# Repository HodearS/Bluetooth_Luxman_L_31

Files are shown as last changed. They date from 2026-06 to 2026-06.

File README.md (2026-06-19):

### 🇫🇷 Version Française
                    
# Luxman L-31 - Module Bluetooth & DAC Interne

Ce dépôt contient les fichiers de conception matérielle d'une carte d'extension Bluetooth conçue spécifiquement pour s'intégrer à l'intérieur d'un amplificateur intégré Luxman L-31.

L'objectif est d'ajouter une connectivité sans fil moderne (aptX-HD) sans dénaturer l'esthétique d'origine de l'appareil ni altérer la qualité de son chemin analogique.

## Architecture technique

La carte s'alimente directement sur le rail de puissance interne de l'amplificateur (environ 40V DC). Le basculement du signal audio est géré par un relais de signal pour garantir que les entrées analogiques d'origine restent totalement isolées lorsque le module est inactif.

Points clés de la conception :
* **Alimentation :** Utilisation d'un régulateur abaisseur (Buck) acceptant jusqu'à 65V en entrée pour tolérer les variations du rail d'alimentation du Luxman.
* **CEM et Bruit :** Le convertisseur Buck fonctionne en mode "Forced PWM" (fréquence fixe de 400 kHz) afin de repousser le bruit de découpage hors de la bande audible. Le routage sur 4 couches inclut des plans de masse dédiés, du via stitching et des zones d'exclusion RF strictes autour de l'antenne.
* **Chemin audio :** Les composants passifs traitant le signal analogique en sortie de DAC utilisent des condensateurs à diélectrique C0G/NP0 et des résistances à couche mince (thin film) pour éviter l'introduction de distorsions harmoniques.

## Spécifications matérielles

* **Logiciel CAO :** KiCad 10
* **PCB :** 4 couches
* **Régulateur 5V :** Texas Instruments LMR51606XFDBVR
* **LDO 3.3V :** Texas Instruments TPS7A2033PDBVR (avec décharge active)
* **DAC :** ESS Technology ES9023P
* **Module Bluetooth :** Feasycom FSC-BT1026E (sortie I2S/PCM)
* **Relais Audio :** Omron G6K-2F-Y DC3

## Structure du dépôt

Ce dépôt héberge uniquement les fichiers sources du projet KiCad (`.kicad_pro`, `.kicad_sch`, `.kicad_pcb` et BOM). Les fichiers de fabrication (Gerbers, fichiers de placement CPL) ne sont pas versionnés.

## Avertissement de sécurité

L'installation de ce module implique d'intervenir à l'intérieur d'un amplificateur relié au secteur et de manipuler des tensions continues de puissance. Ces modifications s'adressent à des personnes ayant les compétences requises en électronique. Toute modification est effectuée à vos propres risques.

### 🇬🇧 English Version

# Luxman L-31 - Internal Bluetooth & DAC Module

This repository contains the hardware design files for a Bluetooth extension board specifically designed to be integrated inside a Luxman L-31 integrated amplifier.

The goal is to add modern wireless connectivity (aptX-HD) without altering the original aesthetics of the device or degrading its analog signal path.

## Technical Architecture

The board is powered directly from the amplifier's internal power rail (approx. 40V DC). Audio signal switching is handled by a signal relay to ensure the original analog inputs remain completely isolated when the module is inactive.

Key design points:
* **Power Supply:** Use of a step-down (Buck) regulator accepting up to 65V input to tolerate fluctuations in the Luxman's power rail.
* **EMC and Noise:** The Buck converter operates in "Forced PWM" mode (fixed 400 kHz frequency) to push switching noise out of the audible band. The 4-layer routing includes dedicated ground planes, via stitching, and strict RF keep-out zones around the antenna.
* **Audio Path:** Passive components handling the analog signal at the DAC output use C0G/NP0 dielectric capacitors and thin film resistors to prevent the introduction of harmonic distortion.

## Hardware Specifications

* **CAD Software:** KiCad 10
* **PCB:** 4 layers
* **5V Regulator:** Texas Instruments LMR51606XFDBVR
* **3.3V LDO:** Texas Instruments TPS7A2033PDBVR (with active discharge)
* **DAC:** ESS Technology ES9023P
* **Bluetooth Module:** Feasycom FSC-BT1026E (I2S/PCM output)
* **Audio Relay:** Omron G6K-2F-Y DC3

## Repository Structure

This repository hosts only the KiCad project source files (`.kicad_pro`, `.kicad_sch`, `.kicad_pcb` and BOM). Manufacturing files (Gerbers, CPL placement files) are not versioned.

## Safety Warning

Installing this module involves working inside a mains-connected amplifier and handling high-power DC voltages. These modifications are intended for individuals with the required electronics skills. All modifications are performed at your own risk.

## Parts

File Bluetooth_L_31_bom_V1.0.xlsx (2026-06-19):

Component | References | Description | Value | Footprint | Quantity Per PCB | Prix/unité | Total | Quantité/commande | Total/commande
1 | C15 | GRM2165C2A331JA01D | 330pF | C_0805_2012Metric | 1 | 0.074 | 0.074 | 10 | 0.74
2 | C5 C7 | 08051A472KAT2A | 4700pF | C_0805_2012Metric | 2 | 0.295 | 0.59 | 10 | 2.95
3 | C1 C11 C14 C23 C24 | CL21B104KCFSFNE | 100nF | C_0805_2012Metric | 5 | 0.027 | 0.135 | 20 | 0.54
4 | C2 C3 C9 C10 C13 C16 C17 C22 | CL21B105KBFNNNF | 1uF | C_0805_2012Metric | 8 | 0.038 | 0.304 | 20 | 0.76
5 | C19 | CL21B225KAFNNNF | 2.2uF | C_0805_2012Metric | 1 | 0.041 | 0.041 | 10 | 0.41
6 | C6 C8 | GRM32DL8EL475KE07L | 4.7uF | C_1210_3225Metric | 2 | 0.0361 | 0.0722 | 10 | 0.361
7 | C12 C20 C21 | GRM21BZ71E106KE15K | 10uF | C_0805_2012Metric | 3 | 0.119 | 0.357 | 10 | 1.19
8 | C4 | CL32B106KMVNNWE | 10uF | C_1210_3225Metric | 1 | 0.38 | 0.38 | 10 | 3.8
9 | C18 | CL32B226KAJNNNE | 22uF | C_1210_3225Metric | 1 | 0.238 | 0.238 | 10 | 2.38
10 | D3 | 100V 0.15A standard switching diode, DO-35 | 1N4148 | D_SOD-123 | 1 | 0.087 | 0.087 | 10 | 0.87
11 | D1 | B360-13-F | B360 | D_SMC | 1 | 0.35 | 0.35 | 10 | 3.5
12 | D4 | 150080GS75000 | LED | LED_0805_2012Metric | 1 | 0.161 | 0.161 | 10 | 1.61
13 | D2 | SMAJ48A | SMAJ48A | D_SMA | 1 | 0.275 | 0.275 | 10 | 2.75
14 | J1 | 1727010 | 1727010 | PHOENIX_1727010 | 1 | 0.972 | 0.972 | 2 | 1.944
15 | J2 J3 | 1727023 | 1727023 | PHOENIX_1727023 | 2 | 1.45 | 2.9 | 4 | 5.8
16 | J4 | B3B-PH-SM4-TB(LF)(SN) | B3B-PH-SM4-TB_LF__SN_ | JST_B3B-PH-SM4-TB_LF__SN_ | 1 | 0.387 | 0.387 | 2 | 0.774
17 | K1 | G6K-2F-Y-DC3 | G6K-2F-Y DC3 | Relay_DPDT_Omron_G6K-2F-Y | 1 | 3.15 | 3.15 | 2 | 6.3
18 | L1 | LQH32PN1R0NN0L | 820nH | L_1210_3225Metric | 1 | 0.188 | 0.188 | 10 | 1.88
19 | L2 | SRN4018-470M | 47uH | L_Bourns-SRN4018 | 1 | 0.264 | 0.264 | 10 | 2.64
20 | Q1 Q2 | 2N7002LT1G | 2N7002 | SOT-23-3 | 2 | 0.164 | 0.328 | 10 | 1.64
21 | R6 R9 | Resistor, small symbol | 100m | R_0805_2012Metric | 2 (DNF) |  |  |  | 0
22 | R3 | Resistor, small symbol | 1 | R_0805_2012Metric | 1 (DNF) |  |  |  | 0
23 | R10 | RC0805FR-073RL | 3 | R_0805_2012Metric | 1 | 0.024 | 0.024 | 10 | 0.24
24 | R4 R20 R21 R22 | RC0805FR-0733RL | 33 | R_0805_2012Metric | 4 | 0.015 | 0.06 | 10 | 0.15
25 | R2 R5 | ERA-6AEB471V | 470 | R_0805_2012Metric | 2 | 0.064 | 0.128 | 10 | 0.64
26 | R14 R17 R19 | RC0805FR-071KL | 1k | R_0805_2012Metric | 3 | 0.018 | 0.054 | 10 | 0.18
27 | R1 R8 R16 R23 | RC0805FR-0710KL | 10k | R_0805_2012Metric | 4 | 0.018 | 0.072 | 10 | 0.18
28 | R12 | RC0805FR-0719K1L | 19.1k | R_0805_2012Metric | 1 | 0.017 | 0.017 | 10 | 0.17
29 | R11 R13 R15 R18 | RC0805FR-07100KL | 100k | R_0805_2012Metric | 4 | 0.018 | 0.072 | 10 | 0.18
30 | R7 | RC0805FR-07280KL | 280k | R_0805_2012Metric | 1 | 0.015 | 0.015 | 10 | 0.15
31 | SW1 | B3U-1000PM | B3U-1000P(M) | SW_B3U-1000PM | 1 | 1.08 | 1.08 | 1 | 1.08
32 | U5 | FSC-BT1026E | FSC-BT1026E | FSC-BT1026x | 1 | 8 | 8 | 1 | 8
33 | U3 | LMR51606XFQDBVRQ1 | LMR51606FPWM | SOT-23-6 | 1 | 1.4 | 1.4 | 1 | 1.4
34 | U1 U2 | TPS7A2033PDBVR | ~ | SOT-23-5 | 2 | 0.224 | 0.448 | 5 | 1.12
35 | U4 | ES9023P | ~ | SOP-16_4.4x10.4mm_P1.27mm | 1 | 1.19 | 1.19 | 4 | 4.76
36 | Y1 | SG-210STF 50.0000ML | SG-210STF 50.0000ML | Oscillator_SMD_SeikoEpson_SG210-4Pin_2.5x2.0mm | 1 | 2.12 | 2.12 | 1 | 2.12
 |  |  |  |  |  | Coût total/cartes | 25.9332 | 283 | 63.209
Component Groups: | 36
Component Count: | 67
Fitted Components: | 64
Number of PCBs: | 1
Total components: | 64
Schematic Version: | V1.0
Schematic Date: | 2026-06-17
BoM Date: | 2026-06-19T23:25:48
Schematic Source: | Bluetooth_L_31.kicad_sch
KiCad Version: | Eeschema 10.0.3

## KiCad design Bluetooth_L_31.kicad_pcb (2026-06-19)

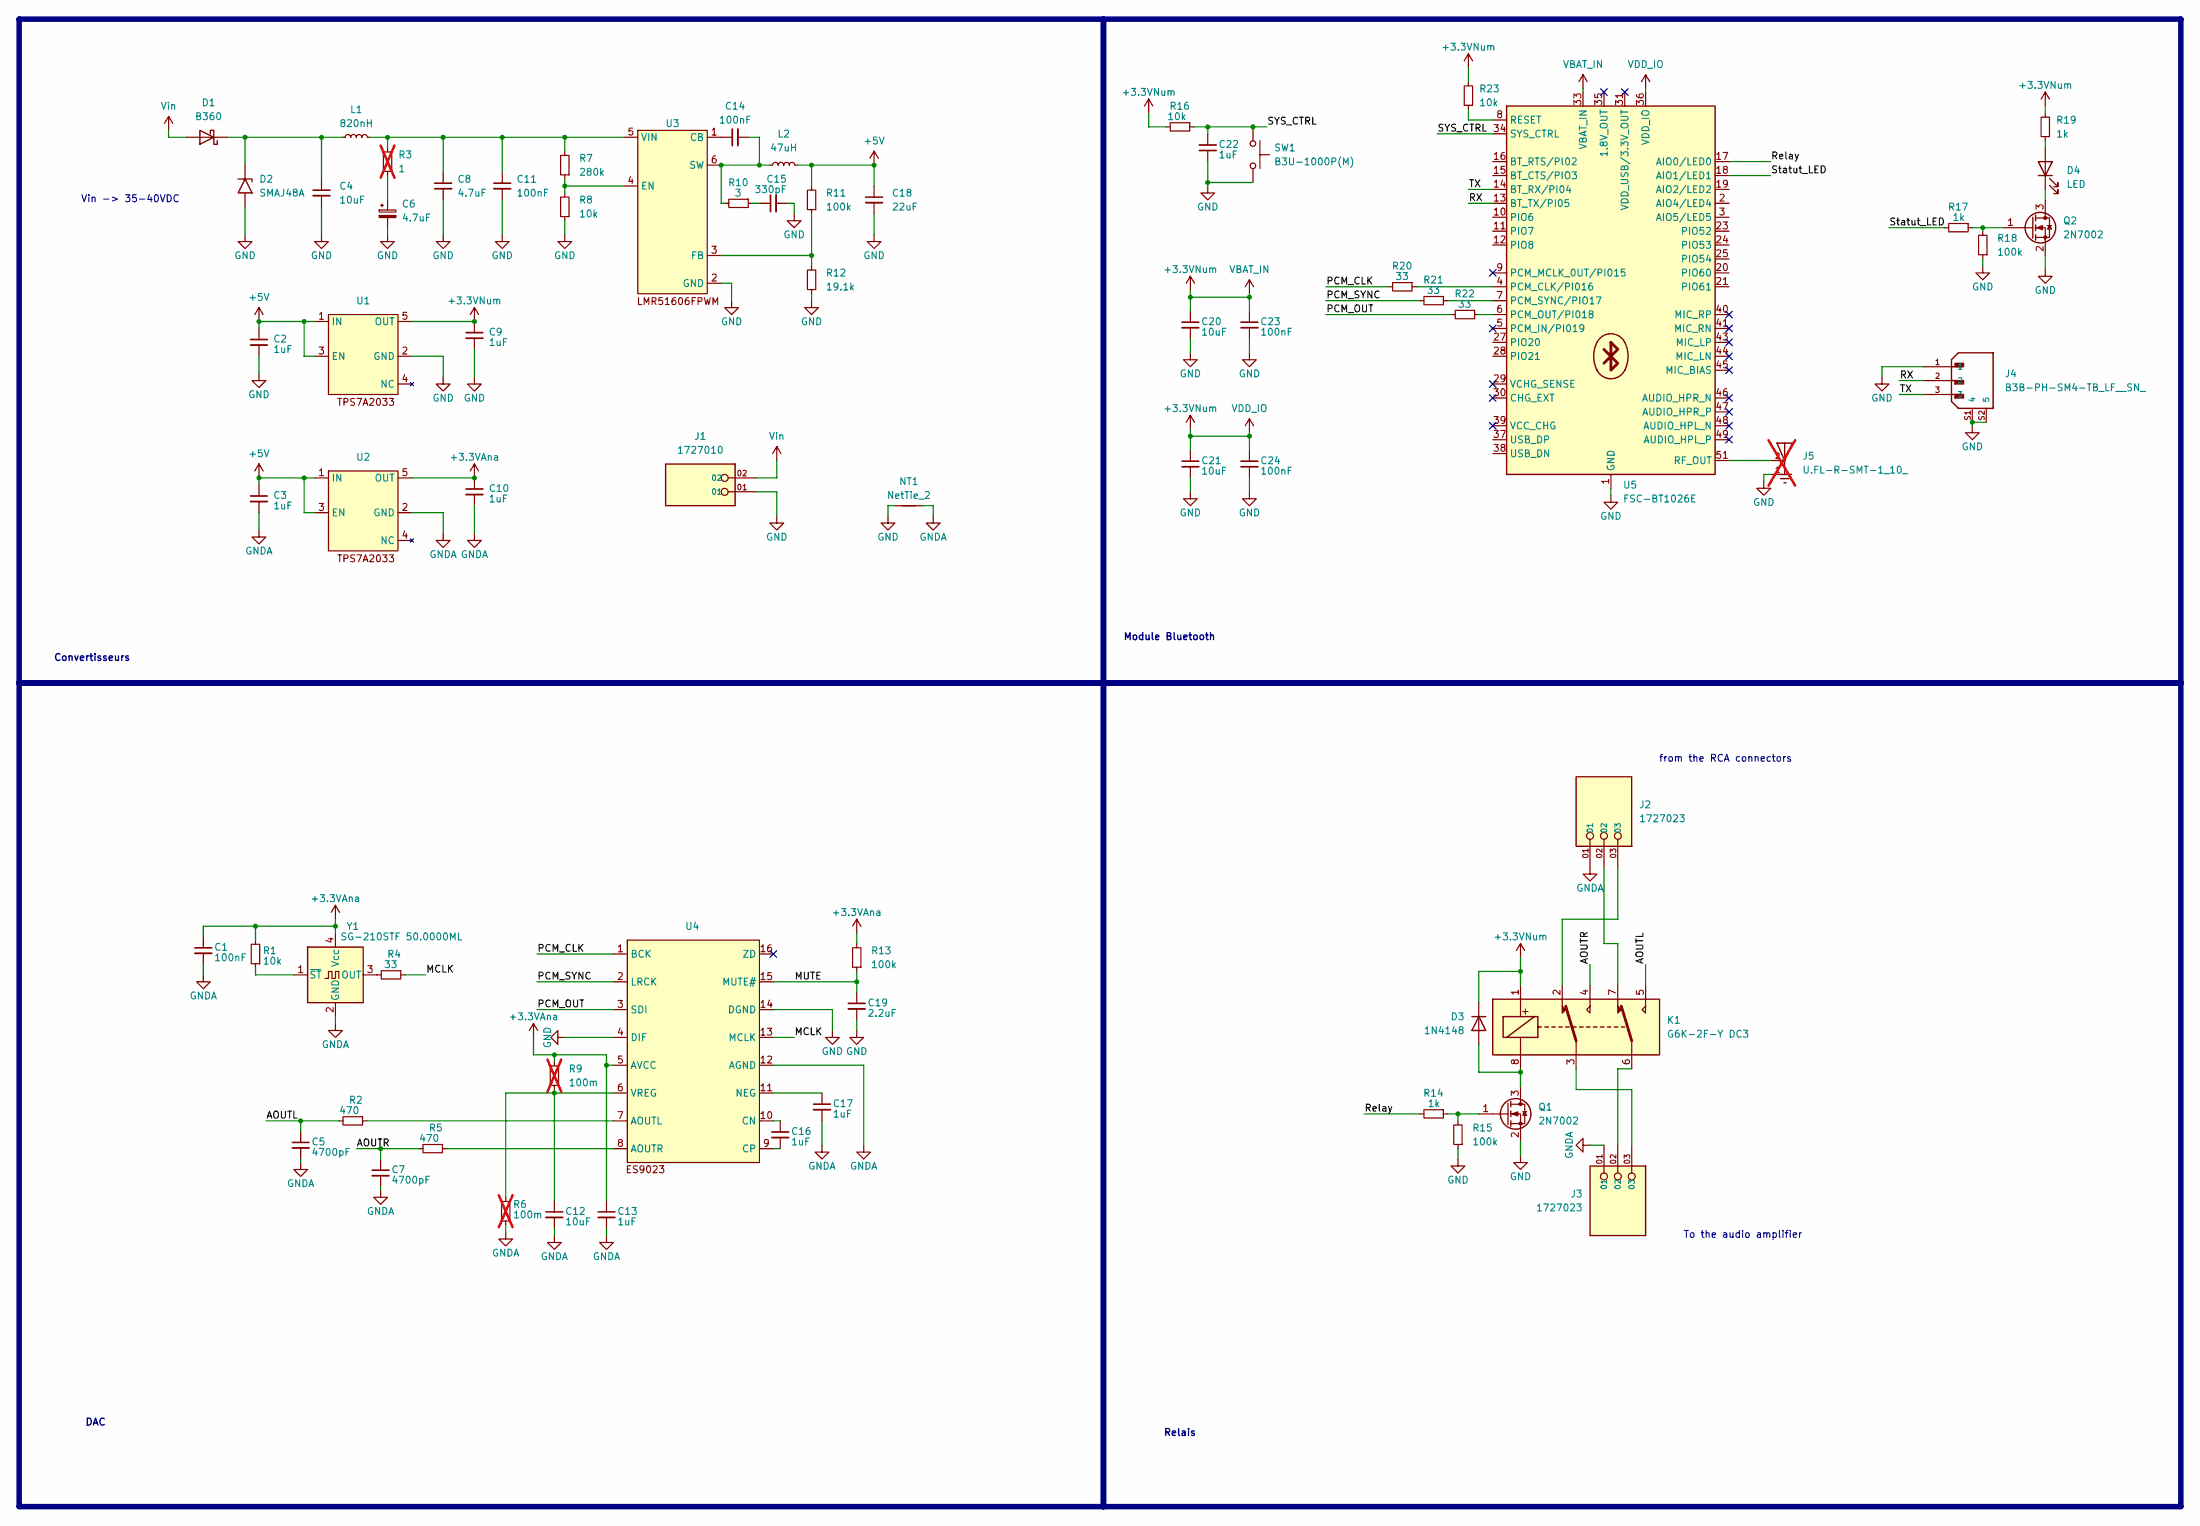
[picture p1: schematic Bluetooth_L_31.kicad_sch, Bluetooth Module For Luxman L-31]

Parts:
C1, C11, C14, C23, C24: 100nF; C_0805_2012Metric
C2, C3, C9, C10, C13, C16, C17, C22: 1uF; C_0805_2012Metric
C4: 10uF; C_1210_3225Metric
C5, C7: 4700pF; C_0805_2012Metric
C6, C8: 4.7uF; C_1210_3225Metric
C12, C20, C21: 10uF; C_0805_2012Metric
C15: 330pF; C_0805_2012Metric
C18: 22uF; C_1210_3225Metric
C19: 2.2uF; C_0805_2012Metric
D1: B360; D_SMC
D2: SMAJ48A; D_SMA
D3: 1N4148; D_SOD-123
D4: LED; LED_0805_2012Metric
J1: 1727010; PHOENIX_1727010; PARTREV 03.03.2021
J2, J3: 1727023; PHOENIX_1727023; PARTREV 03.03.2021
J4: B3B-PH-SM4-TB_LF__SN_; JST_B3B-PH-SM4-TB_LF__SN_; PARTREV N/A
J5: U.FL-R-SMT-1_10_; HRS_U.FL-R-SMT-1_10_; not fitted
K1: G6K-2F-Y DC3; Relay_DPDT_Omron_G6K-2F-Y
L1: 820nH; L_1210_3225Metric
L2: 47uH; L_Bourns-SRN4018
NT1: NetTie_2; NetTie-2_SMD_Pad2.0mm
Q1, Q2: 2N7002; SOT-23-3
R1, R8, R16, R23: 10k; R_0805_2012Metric
R2, R5: 470; R_0805_2012Metric
R3: 1; R_0805_2012Metric; not fitted
R4, R20, R21, R22: 33; R_0805_2012Metric
R6, R9: 100m; R_0805_2012Metric; not fitted
R7: 280k; R_0805_2012Metric
R10: 3; R_0805_2012Metric
R11, R13, R15, R18: 100k; R_0805_2012Metric
R12: 19.1k; R_0805_2012Metric
R14, R17, R19: 1k; R_0805_2012Metric
SW1: B3U-1000P(M); SW_B3U-1000PM
U1, U2: SOT-23-5
U3: LMR51606FPWM; SOT-23-6
U4: SOP-16_4.4x10.4mm_P1.27mm
U5: FSC-BT1026E; FSC-BT1026x
Y1: SG-210STF 50.0000ML; Oscillator_SMD_SeikoEpson_SG210-4Pin_2.5x2.0mm

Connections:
+3.3VAna: C1.1, C10.1, C13.1, R1.2, R9.2, R13.2, U2.5 (OUT), U4.5 (AVCC), Y1.4 (Vcc)
+3.3VNum: C9.1, C20.1, C21.1, C23.1, C24.1, D3.1 (K), K1.1, R16.2, R19.2, R23.2, U1.5 (OUT), U5.33 (VBAT_IN), U5.36 (VDD_IO)
+5V: C2.1, C3.1, C18.1, L2.2, R11.2, U1.1 (IN), U1.3 (EN), U2.1 (IN), U2.3 (EN)
/AOUTL: C5.1, K1.5, R2.2
/AOUTR: C7.1, K1.4, R5.2
/MCLK: R4.1, U4.13 (MCLK)
/MUTE: C19.1, R13.1, U4.15 (MUTE#)
/PCM_CLK: R20.2, U4.1 (BCK)
/PCM_OUT: R22.2, U4.3 (SDI)
/PCM_SYNC: R21.2, U4.2 (LRCK)
/RX: J4.2, U5.13 (BT_TX/PI05)
/Relay: R14.2, U5.17 (AIO0/LED0)
/SYS_CTRL: C22.1, R16.1, SW1.1, U5.34 (SYS_CTRL)
/Statut_LED: R17.2, U5.18 (AIO1/LED1)
/TX: J4.3, U5.14 (BT_RX/PI04)
GND: C2.2, C4.2, C6.2, C8.2, C9.2, C11.2, C15.2, C18.2, C19.2, C20.2, C21.2, C22.2, C23.2, C24.2, D2.2 (A2), J1.01, J4.1, J4.S1 (4), J4.S2 (5), J5.1, J5.3, NT1.1, Q1.2 (S), Q2.2 (S), R8.1, R12.1, R15.1, R18.1, SW1.2, U1.2 (GND), U3.2 (GND), U4.4 (DIF), U4.14 (DGND), U5.1 (GND), U5.22 (GND), U5.32 (GND), U5.50 (GND), U5.52 (GND)
GNDA: C1.2, C3.2, C5.2, C7.2, C10.2, C12.2, C13.2, C17.2, J2.01, J3.01, NT1.2, R6.1, U2.2 (GND), U4.12 (AGND), Y1.2 (GND)
unnamed: C6.1, R3.1
unnamed: C15.1, R10.1
unnamed: C4.1, D1.1 (K), D2.1 (A1), L1.1
unnamed: D3.2 (A), K1.8, Q1.3 (D)
unnamed: D4.2 (A), R19.1
unnamed: D4.1 (K), Q2.3 (D)
unnamed: J2.02, K1.7
unnamed: J2.03, K1.2
unnamed: J3.02, K1.6
unnamed: J3.03, K1.3
unnamed: Q1.1 (G), R14.1, R15.2
unnamed: Q2.1 (G), R17.1, R18.2
unnamed: C14.1, U3.1 (CB)
unnamed: R7.1, R8.2, U3.4 (EN)
unnamed: R11.1, R12.2, U3.3 (FB)
unnamed: C14.2, L2.1, R10.2, U3.6 (SW)
unnamed: C8.1, C11.1, L1.2, R3.2, R7.2, U3.5 (VIN)
unnamed: R2.1, U4.7 (AOUTL)
unnamed: R5.1, U4.8 (AOUTR)
unnamed: C16.1, U4.10 (CN)
unnamed: C16.2, U4.9 (CP)
unnamed: C17.1, U4.11 (NEG)
unnamed: C12.1, R6.2, R9.1, U4.6 (VREG)
unnamed: R20.1, U5.4 (PCM_CLK/PI016)
unnamed: R22.1, U5.6 (PCM_OUT/PI018)
unnamed: R21.1, U5.7 (PCM_SYNC/PIO17)
unnamed: R23.1, U5.8 (RESET)
unnamed: J5.2, U5.51 (RF_OUT)
unnamed: R4.2, Y1.3 (OUT)
unnamed: R1.1, Y1.1 (~ST)
Vin: D1.2 (A), J1.02

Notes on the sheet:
from the RCA connectors
DAC
Module Bluetooth
Vin -> 35-40VDC
Convertisseurs
To the audio amplifier
Relais

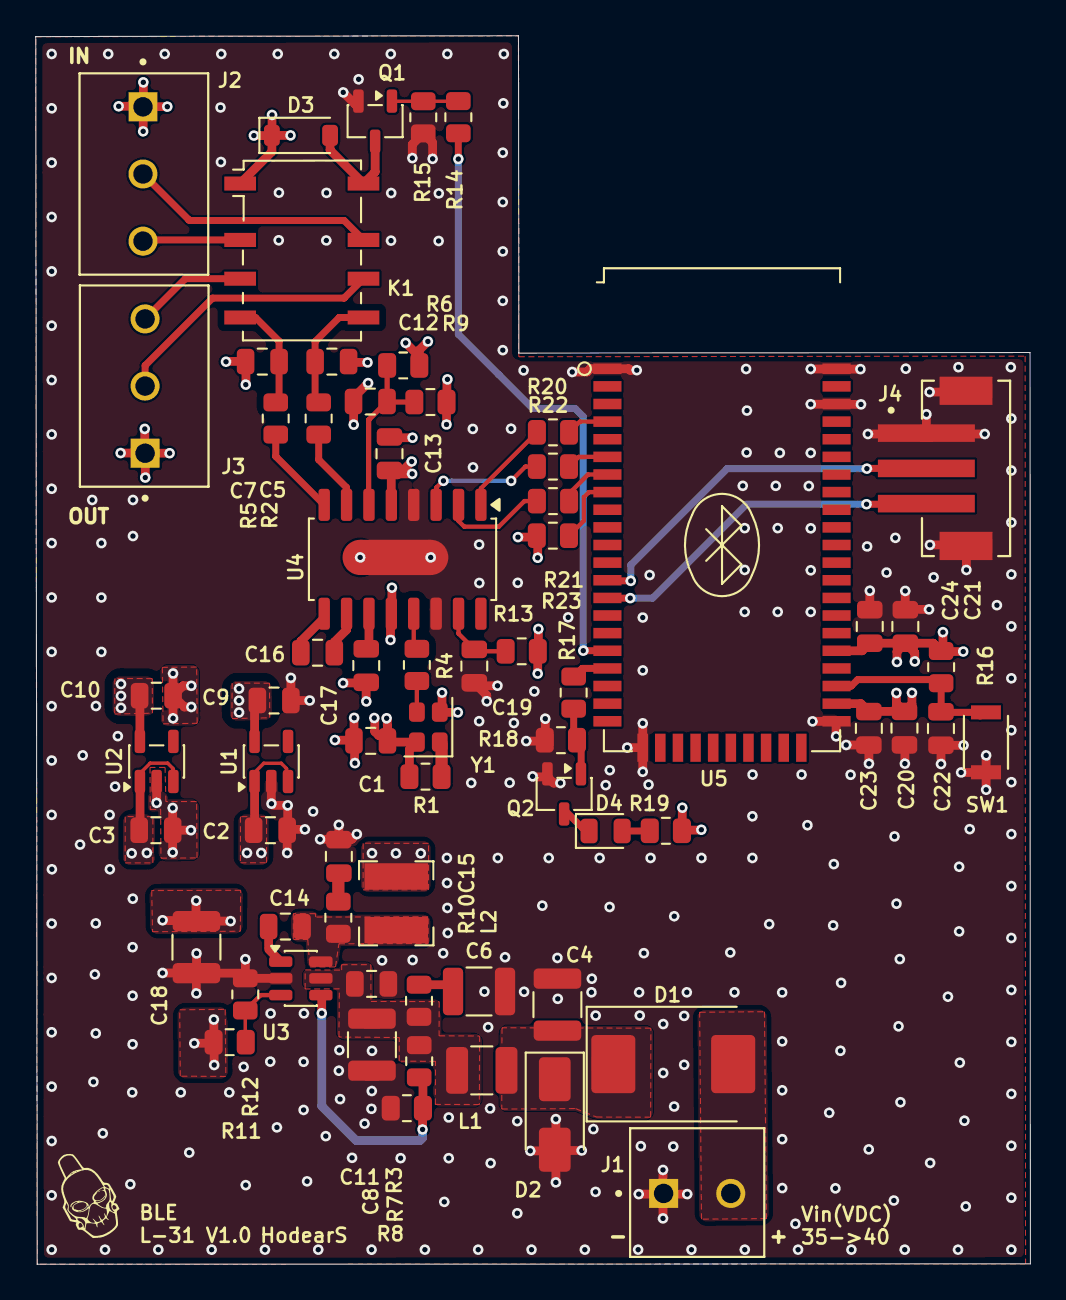
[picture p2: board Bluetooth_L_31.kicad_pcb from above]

Board: 4 copper layers, 56.4 x 69.7 mm, 68 parts (0 on the bottom side), 47 nets.
